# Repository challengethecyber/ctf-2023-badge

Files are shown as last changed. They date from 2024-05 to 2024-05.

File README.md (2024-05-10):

# ctf-2023-badge
Badge related files for CTC 2023 CTF



## Info

- Custom PCB with RP2040 based on [rp-micro](https://github.com/siderakb/rp-micro) project.
- View [IBOM](https://challengethecyber.github.io/ctf-2023-assets/ducky/ibom.html)

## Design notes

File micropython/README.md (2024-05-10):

uf2 created from
 - circuitpython base
 - duckyfs files added on top of it
 - filesystem renamed (in windows) to DUCKY

then ran:
# sudo picotool save -a -f -t uf2 ducky.uf2

to load it onto another ducky:
# sudo picotool load ducky.uf2

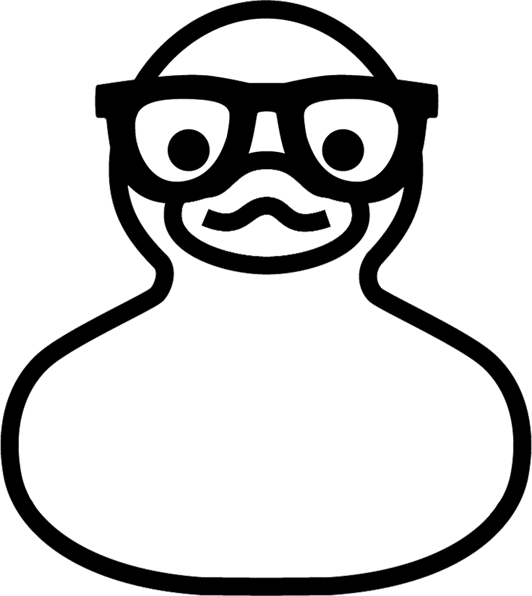
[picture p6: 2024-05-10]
hardware/psd/v2-duck-10cm-lines-noarms.png

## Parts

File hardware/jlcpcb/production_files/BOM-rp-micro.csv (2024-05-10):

Comment | Designator | Footprint | LCSC
1k | R3,R4,R9 | R_0402_1005Metric | C11702
B5817 | D1 | D_SOD-323_HandSoldering | C123899
20pF | C3,C4 | C_0402_1005Metric | C1554
RP2040 | U1 | QFN-56-1EP_7x7mm_P0.4mm_EP3.2x3.2mm | C2040
BOOT | SW1,SW2 | SW_SPST_B3U-1000P | C231329
27 | R1,R2 | R_0402_1005Metric | C25100
10k | R5,R8 | R_0402_1005Metric | C25744
5.1k | R6,R7 | R_0402_1005Metric | C25905
500mA, 6V | F1 | Fuse_0805_2012Metric | C269104
W25Q64JVXGIQ | U2 | XSON-8 (4x4mm) | C2940195
100nF | C1,C10,C11,C12,C15,C2,C5,C6,C8,C9 | C_0402_1005Metric | C307331
RT9013-33GB | U3 | SOT-23-5 | C47773
1uF | C13,C14,C16,C7 | C_0402_1005Metric | C52923
BLUE | LD1 | LED_0603_1608Metric | C72041
12MHz | Y1 | Crystal_SMD_3225-4Pin_3.2x2.5mm | C9002
USB_C_Receptacle_USB2.0 | J1 | USB_C_Receptacle_TYPE-C-31-M-12

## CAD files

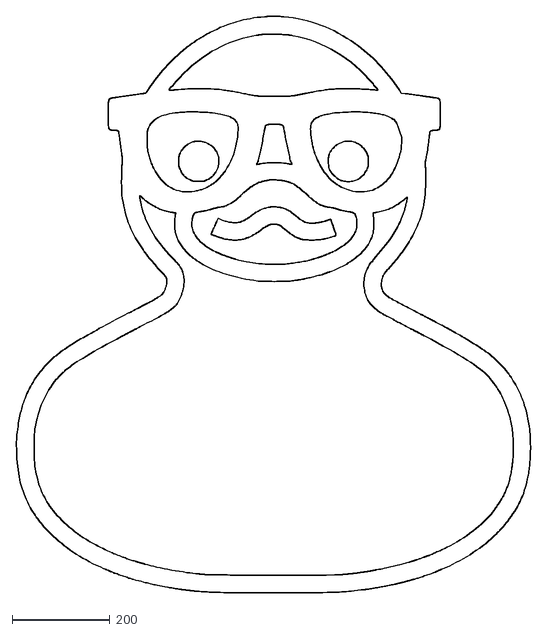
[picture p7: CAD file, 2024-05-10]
hardware/psd/v2-duck-10cm-lines-noarms.dxf
1051.7 x 1180.5

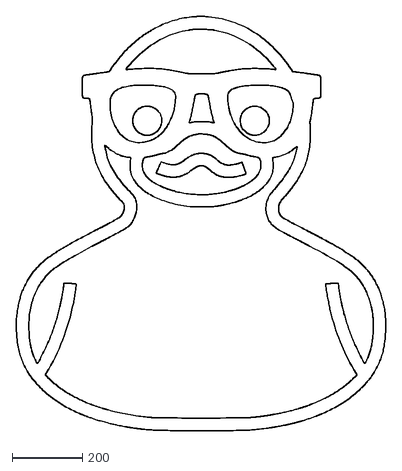
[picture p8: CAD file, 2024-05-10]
hardware/psd/v2-duck-10cm-lines.dxf
1051.7 x 1180.5

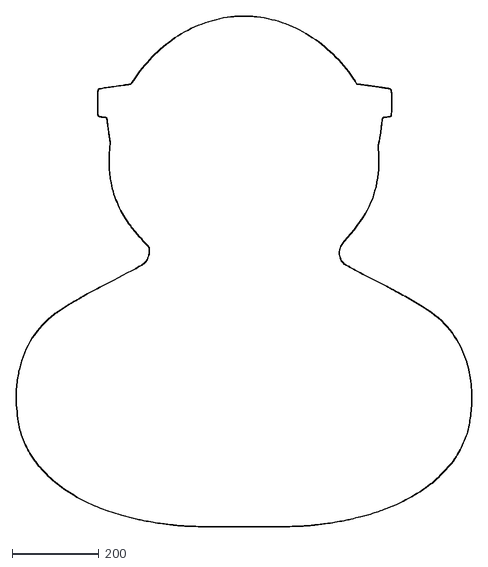
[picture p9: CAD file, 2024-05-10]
hardware/psd/v2-duck-10cm-bw.dxf
1052.4 x 1178.8

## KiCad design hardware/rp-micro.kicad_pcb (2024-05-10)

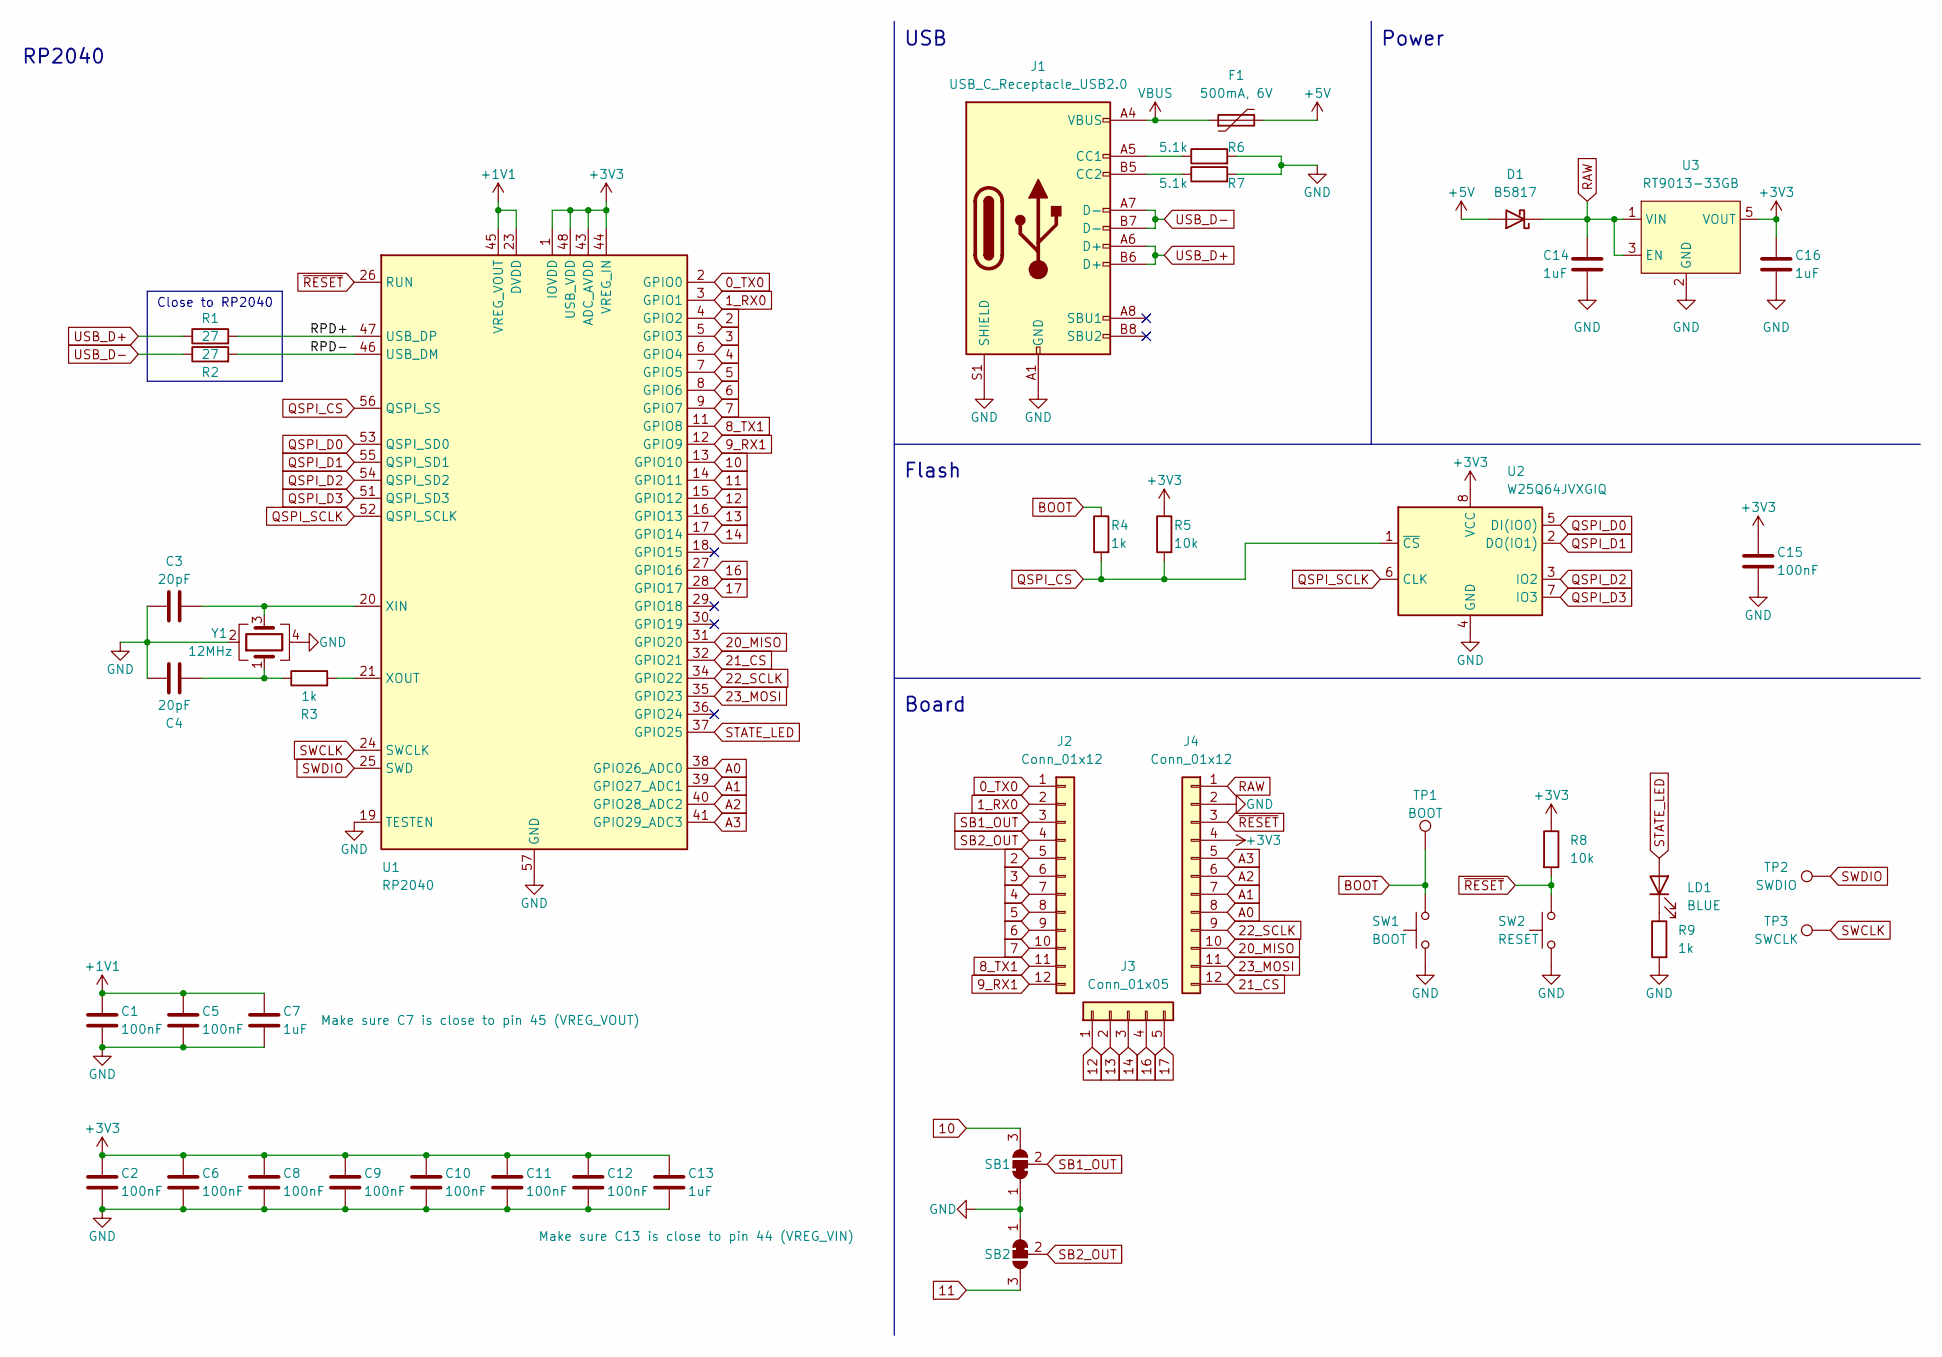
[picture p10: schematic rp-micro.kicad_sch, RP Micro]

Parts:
C1, C2, C5, C6, C8, C9, C10, C11, C12, C15: 100nF; C_0402_1005Metric; MFR. Part # CL05B104KB54PNC; JLCPCB Part # C307331
C3, C4: 20pF; C_0402_1005Metric; MFR. Part # 0402CG200J500NT; JLCPCB Part # C1554
C7, C13, C14, C16: 1uF; C_0402_1005Metric; MFR. Part # CL05A105KA5NQNC; JLCPCB Part # C52923
D1: B5817; D_SOD-323_HandSoldering; MFR. Part # B5817WS; JLCPCB Part # C123899
F1: 500mA, 6V; Fuse_0805_2012Metric; MFR. Part # SMD0805B050TF; JLCPCB Part # C269104
J1: USB_C_Receptacle_USB2.0; USB Type-C Mid-Mount Receptacle 16P; MFR. Part # 918-418K2024S40000; JLCPCB Part # C168688
J2, J4: Conn_01x12; PinHeader_1x12_P2.54mm_Vertical
J3: Conn_01x05; PinHeader_1x05_P2.54mm_Vertical
LD1: BLUE; LED_0603_1608Metric; MFR. Part # 19-217/BHC-ZL1M2RY/3T; JLCPCB Part # C72041
R1, R2: 27; R_0402_1005Metric; MFR. Part # 0402WGF270JTCE; JLCPCB Part # C25100
R3, R4, R9: 1k; R_0402_1005Metric; MFR. Part # 0402WGF1001TCE; JLCPCB Part # C11702
R5, R8: 10k; R_0402_1005Metric; MFR. Part # 0402WGF1002TCE; JLCPCB Part # C25744
R6, R7: 5.1k; R_0402_1005Metric; MFR. Part # 0402WGF5101TCE; JLCPCB Part # C25905
SB1, SB2: SolderJumper_3_Bridged12; SolderJumper-3_P1.3mm_Bridged12_Pad1.0x1.5mm
SW1: BOOT; SW_SPST_B3U-1000P; MFR. Part # B3U-1000P; JLCPCB Part # C231329
SW2: RESET; SW_SPST_B3U-1000P; MFR. Part # B3U-1000P; JLCPCB Part # C231329
TP1: BOOT; TestPoint_Pad_D2.0mm
TP2: SWDIO; TestPoint_Pad_D2.0mm
TP3: SWCLK; TestPoint_Pad_D2.0mm
U1: RP2040; QFN-56-1EP_7x7mm_P0.4mm_EP3.2x3.2mm; MFR. Part # RP2040; JLCPCB Part # C2040
U2: W25Q64JVXGIQ; XSON-8 (4x4mm); MFR. Part # W25Q64JVXGIQ; JLCPCB Part # C2940195
U3: RT9013-33GB; SOT-23-5; MFR. Part # RT9013-33GB; JLCPCB Part # C47773
Y1: 12MHz; Crystal_SMD_3225-4Pin_3.2x2.5mm; MFR. Part # X322512MSB4SI; JLCPCB Part # C9002

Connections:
0_TX0: J2.1, U1.2 (GPIO0)
1_RX0: J2.2, U1.3 (GPIO1)
2: J2.5, U1.4 (GPIO2)
3: J2.6, U1.5 (GPIO3)
4: J2.7, U1.6 (GPIO4)
5: J2.8, U1.7 (GPIO5)
6: J2.9, U1.8 (GPIO6)
7: J2.10, U1.9 (GPIO7)
8_TX1: J2.11, U1.11 (GPIO8)
9_RX1: J2.12, U1.12 (GPIO9)
10: SB1.3 (B), U1.13 (GPIO10)
11: SB2.3 (B), U1.14 (GPIO11)
12: J3.1, U1.15 (GPIO12)
13: J3.2, U1.16 (GPIO13)
14: J3.3, U1.17 (GPIO14)
16: J3.4, U1.27 (GPIO16)
17: J3.5, U1.28 (GPIO17)
20_MISO: J4.10, U1.31 (GPIO20)
21_CS: J4.12, U1.32 (GPIO21)
22_SCLK: J4.9, U1.34 (GPIO22)
23_MOSI: J4.11, U1.35 (GPIO23)
+1V1: C1.1, C5.1, C7.1, U1.23 (DVDD), U1.45 (VREG_VOUT), U1.50 (DVDD)
+3V3: C2.1, C6.1, C8.1, C9.1, C10.1, C11.1, C12.1, C13.1, C15.1, C16.1, J4.4, R5.1, R8.1, U1.1 (IOVDD), U1.10 (IOVDD), U1.22 (IOVDD), U1.33 (IOVDD), U1.42 (IOVDD), U1.43 (ADC_AVDD), U1.44 (VREG_IN), U1.48 (USB_VDD), U1.49 (IOVDD), U2.8 (VCC), U3.5 (VOUT)
+5V: D1.2 (A), F1.2
/RPD+: R1.2, U1.47 (USB_DP)
/RPD-: R2.2, U1.46 (USB_DM)
A0: J4.8, U1.38 (GPIO26_ADC0)
A1: J4.7, U1.39 (GPIO27_ADC1)
A2: J4.6, U1.40 (GPIO28_ADC2)
A3: J4.5, U1.41 (GPIO29_ADC3)
BOOT: R4.1, SW1.2, TP1.1
GND: C1.2, C2.2, C3.1, C4.1, C5.2, C6.2, C7.2, C8.2, C9.2, C10.2, C11.2, C12.2, C13.2, C14.2, C15.2, C16.2, J1.A1 (GND), J1.A12 (GND), J1.B1 (GND), J1.B12 (GND), J1.S1 (SHIELD), J4.2, R6.2, R7.2, R9.2, SB1.1 (A), SB2.1 (A), SW1.1, SW2.1, U1.19 (TESTEN), U1.57 (GND), U2.4 (GND), U3.2 (GND), Y1.2, Y1.4
unnamed: C3.2, U1.20 (XIN), Y1.3
unnamed: C4.2, R3.1, Y1.1
unnamed: J1.A5 (CC1), R6.1
unnamed: J1.B5 (CC2), R7.1
unnamed: LD1.1 (K), R9.1
unnamed: R3.2, U1.21 (XOUT)
QSPI_CS: R4.2, R5.2, U1.56 (QSPI_SS), U2.1 (~CS)
QSPI_D0: U1.53 (QSPI_SD0), U2.5 (DI(IO0))
QSPI_D1: U1.55 (QSPI_SD1), U2.2 (DO(IO1))
QSPI_D2: U1.54 (QSPI_SD2), U2.3 (IO2)
QSPI_D3: U1.51 (QSPI_SD3), U2.7 (IO3)
QSPI_SCLK: U1.52 (QSPI_SCLK), U2.6 (CLK)
RAW: C14.1, D1.1 (K), J4.1, U3.1 (VIN), U3.3 (EN)
SB1_OUT: J2.3, SB1.2 (C)
SB2_OUT: J2.4, SB2.2 (C)
STATE_LED: LD1.2 (A), U1.37 (GPIO25)
SWCLK: TP3.1, U1.24 (SWCLK)
SWDIO: TP2.1, U1.25 (SWD)
USB_D+: J1.A6 (D+), J1.B6 (D+), R1.1
USB_D-: J1.A7 (D-), J1.B7 (D-), R2.1
VBUS: F1.1, J1.A4 (VBUS), J1.A9 (VBUS), J1.B4 (VBUS), J1.B9 (VBUS)
~RESET: J4.3, R8.2, SW2.2, U1.26 (RUN)

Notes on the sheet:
Flash
Close to RP2040
Power
RP2040
USB
Board

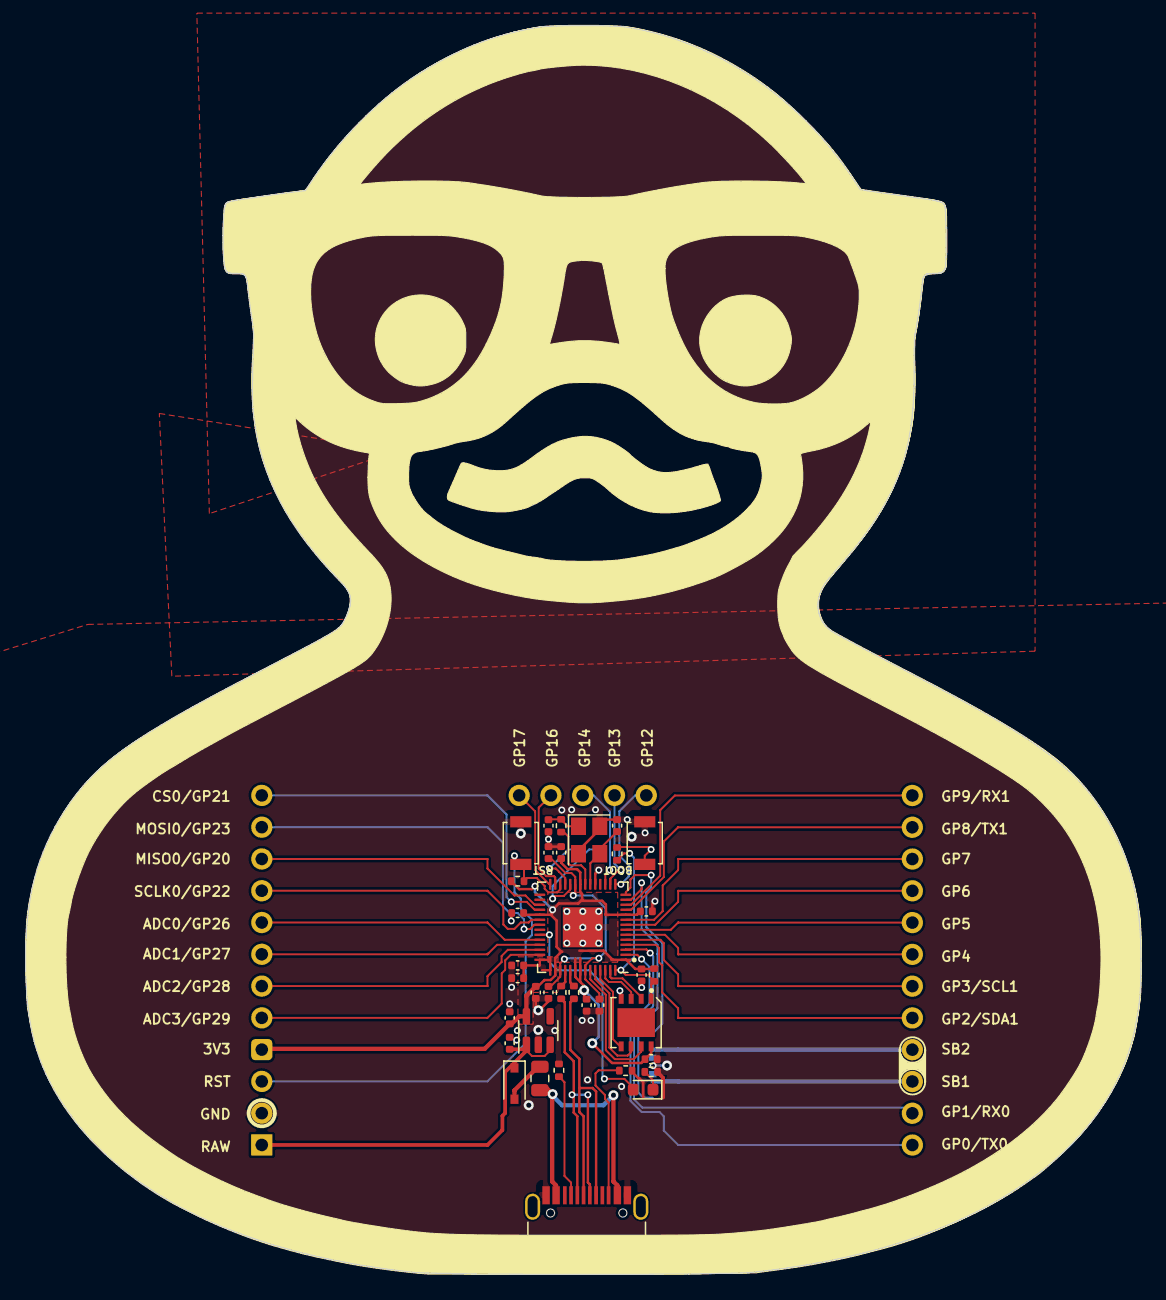
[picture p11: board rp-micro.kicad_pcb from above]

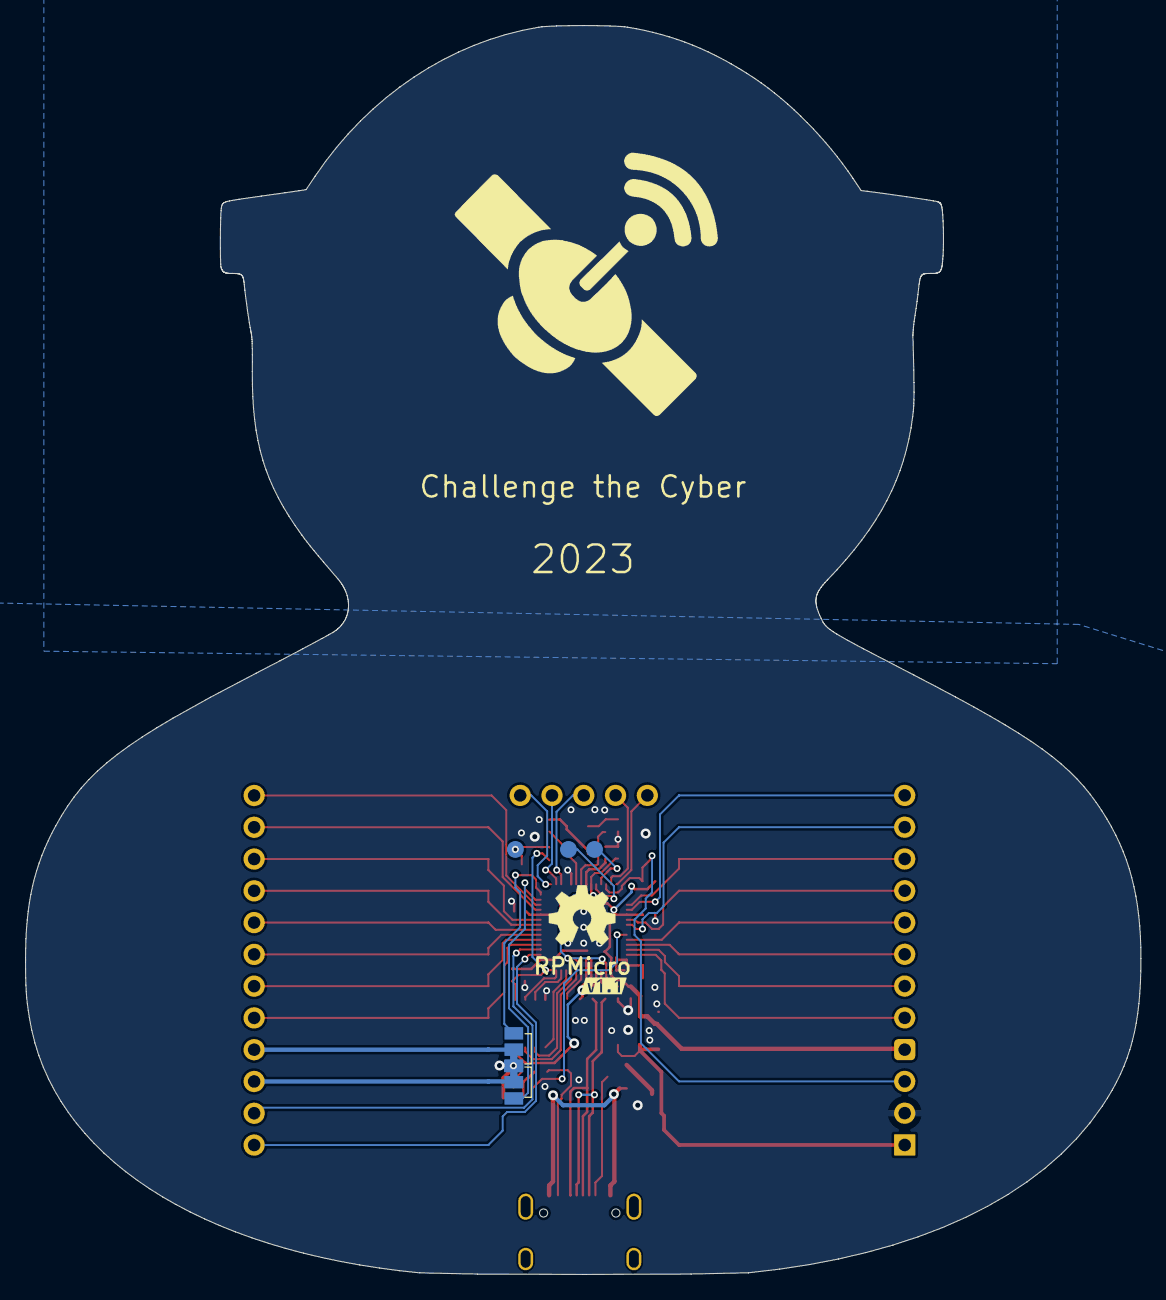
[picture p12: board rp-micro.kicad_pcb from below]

Board: 2 copper layers, 89.2 x 99.8 mm, 44 parts (8 on the bottom side), 54 nets.

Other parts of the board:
kibuzzard-637CA201: G***; kibuzzard-637CA201

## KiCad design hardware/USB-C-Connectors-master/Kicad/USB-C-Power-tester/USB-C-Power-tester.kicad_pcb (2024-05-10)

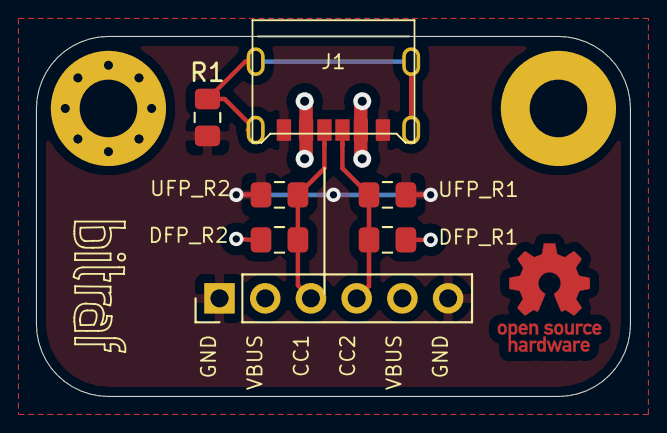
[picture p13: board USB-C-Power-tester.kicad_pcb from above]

Board: 2 copper layers, 33.0 x 20.0 mm, 11 parts (0 on the bottom side), 5 nets.

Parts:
DFP_R1, DFP_R2: DFP; R_0805_2012Metric_Pad1.15x1.40mm_HandSolder
H1: MountingHole; MountingHole_3.2mm_M3_Pad_Via
H3: MountingHole; MountingHole_3.2mm_M3_Pad
J1: USB_C_Receptacle_USB2.0; TYPE-C-31-M-17
L1: Logo_Open_Hardware_Small; OSHW-Logo_5.7x6mm_Copper
L2: Logo_Open_Hardware_Small; Bitraf_logo_3.0_x_7.5_mm
PIN1: Screw_Terminal_01x06; PinHeader_1x06_P2.54mm_Vertical
R1: 1M; R_0805_2012Metric_Pad1.15x1.40mm_HandSolder
UFP_R1, UFP_R2: UFP; R_0805_2012Metric_Pad1.15x1.40mm_HandSolder

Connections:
GND: J1.A12, J1.B12, PIN1.1, PIN1.6, R1.1, UFP_R1.2, UFP_R2.2
unnamed: DFP_R1.1, J1.A5, PIN1.4, UFP_R1.1
unnamed: DFP_R2.1, J1.B5, PIN1.3, UFP_R2.1
unnamed: J1.S1, R1.2
VBUS: DFP_R1.2, DFP_R2.2, J1.A9, J1.B9, PIN1.2, PIN1.5

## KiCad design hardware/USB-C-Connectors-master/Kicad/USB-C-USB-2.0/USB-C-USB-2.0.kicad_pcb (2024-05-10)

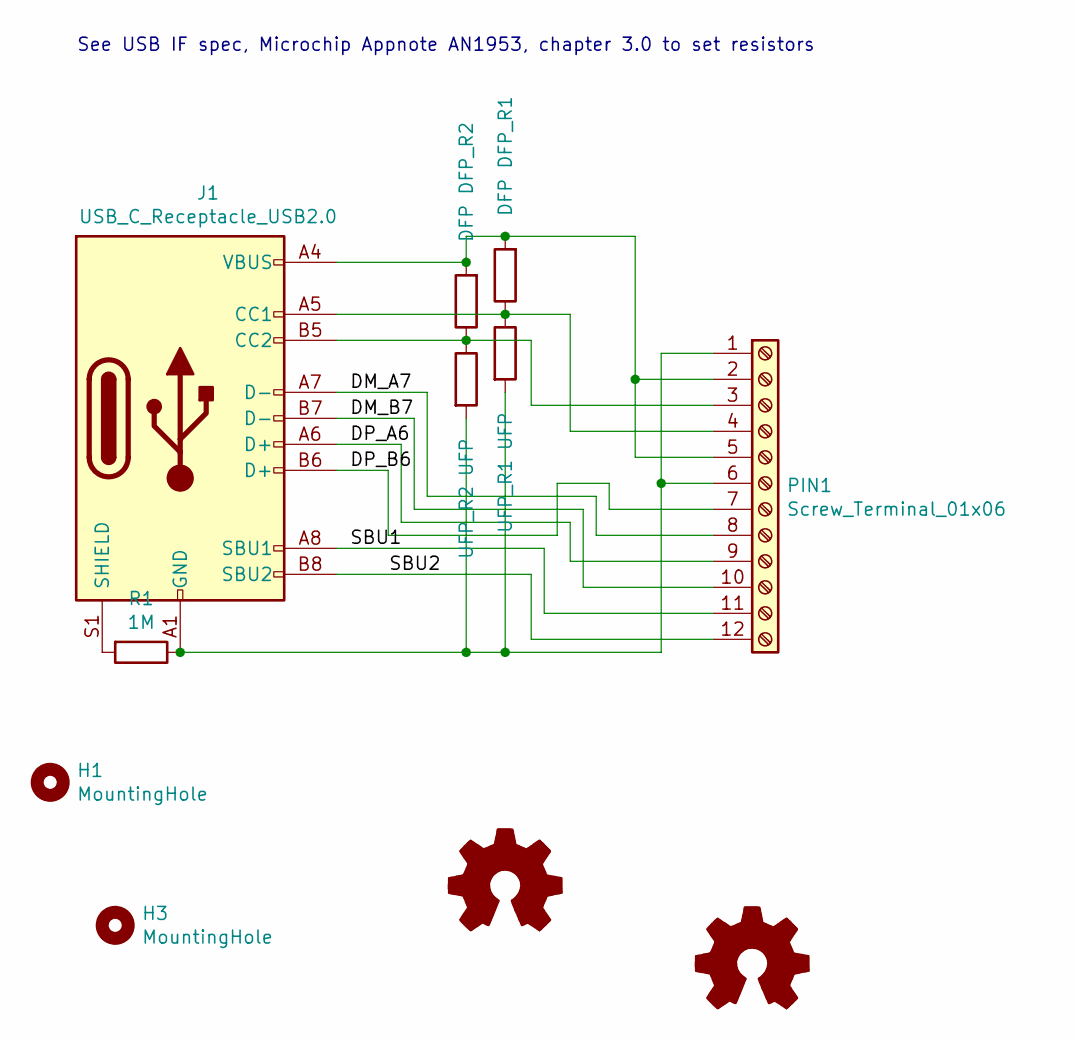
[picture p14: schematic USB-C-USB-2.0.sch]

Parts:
DFP_R1, DFP_R2: DFP; R_0805_2012Metric_Pad1.15x1.40mm_HandSolder
H1: MountingHole; MountingHole_3.2mm_M3_Pad_Via
H3: MountingHole; MountingHole_3.2mm_M3_Pad
J1: USB_C_Receptacle_USB2.0; TYPE-C-31-M-12; MPN TYPE-C-31-M-17
L1: Logo_Open_Hardware_Small; OSHW-Logo_5.7x6mm_SilkScreen
L2: Logo_Open_Hardware_Small; Bitraf_logo_3.0_x_7.5_mm
PIN1: Screw_Terminal_01x06; PinHeader_1x12_P2.54mm_Vertical
R1: 1M; R_0805_2012Metric_Pad1.15x1.40mm_HandSolder
UFP_R1, UFP_R2: UFP; R_0805_2012Metric_Pad1.15x1.40mm_HandSolder

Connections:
/DM_A7: J1.A7 (D-), PIN1.8
/DM_B7: J1.B7 (D-), PIN1.10
/DP_A6: J1.A6 (D+), PIN1.9
/DP_B6: J1.B6 (D+), PIN1.7
/SBU1: J1.A8 (SBU1), PIN1.11
/SBU2: J1.B8 (SBU2), PIN1.12
GND: J1.A1 (GND), J1.A12 (GND), J1.B1 (GND), J1.B12 (GND), PIN1.1, PIN1.6, R1.1, UFP_R1.2, UFP_R2.2
unnamed: DFP_R1.1, J1.A5 (CC1), PIN1.4, UFP_R1.1
unnamed: DFP_R2.1, J1.B5 (CC2), PIN1.3, UFP_R2.1
unnamed: J1.S1 (SHIELD), R1.2
VBUS: DFP_R1.2, DFP_R2.2, J1.A4 (VBUS), J1.A9 (VBUS), J1.B4 (VBUS), J1.B9 (VBUS), PIN1.2, PIN1.5

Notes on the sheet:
See USB IF spec, Microchip Appnote AN1953, chapter 3.0 to set resistors

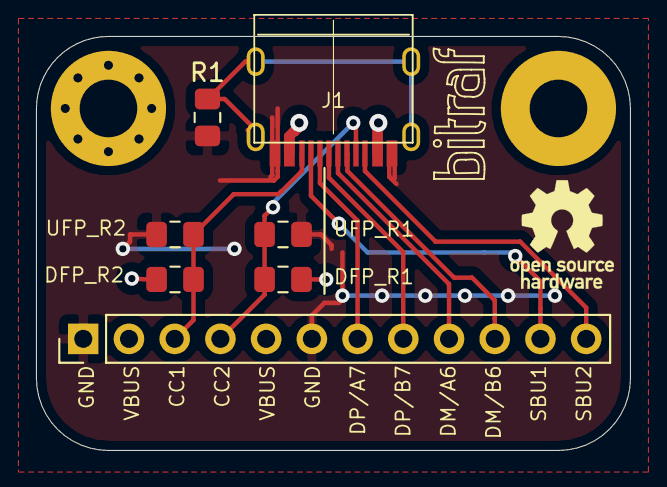
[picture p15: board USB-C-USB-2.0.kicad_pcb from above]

Board: 2 copper layers, 33.0 x 23.0 mm, 11 parts (0 on the bottom side), 11 nets.

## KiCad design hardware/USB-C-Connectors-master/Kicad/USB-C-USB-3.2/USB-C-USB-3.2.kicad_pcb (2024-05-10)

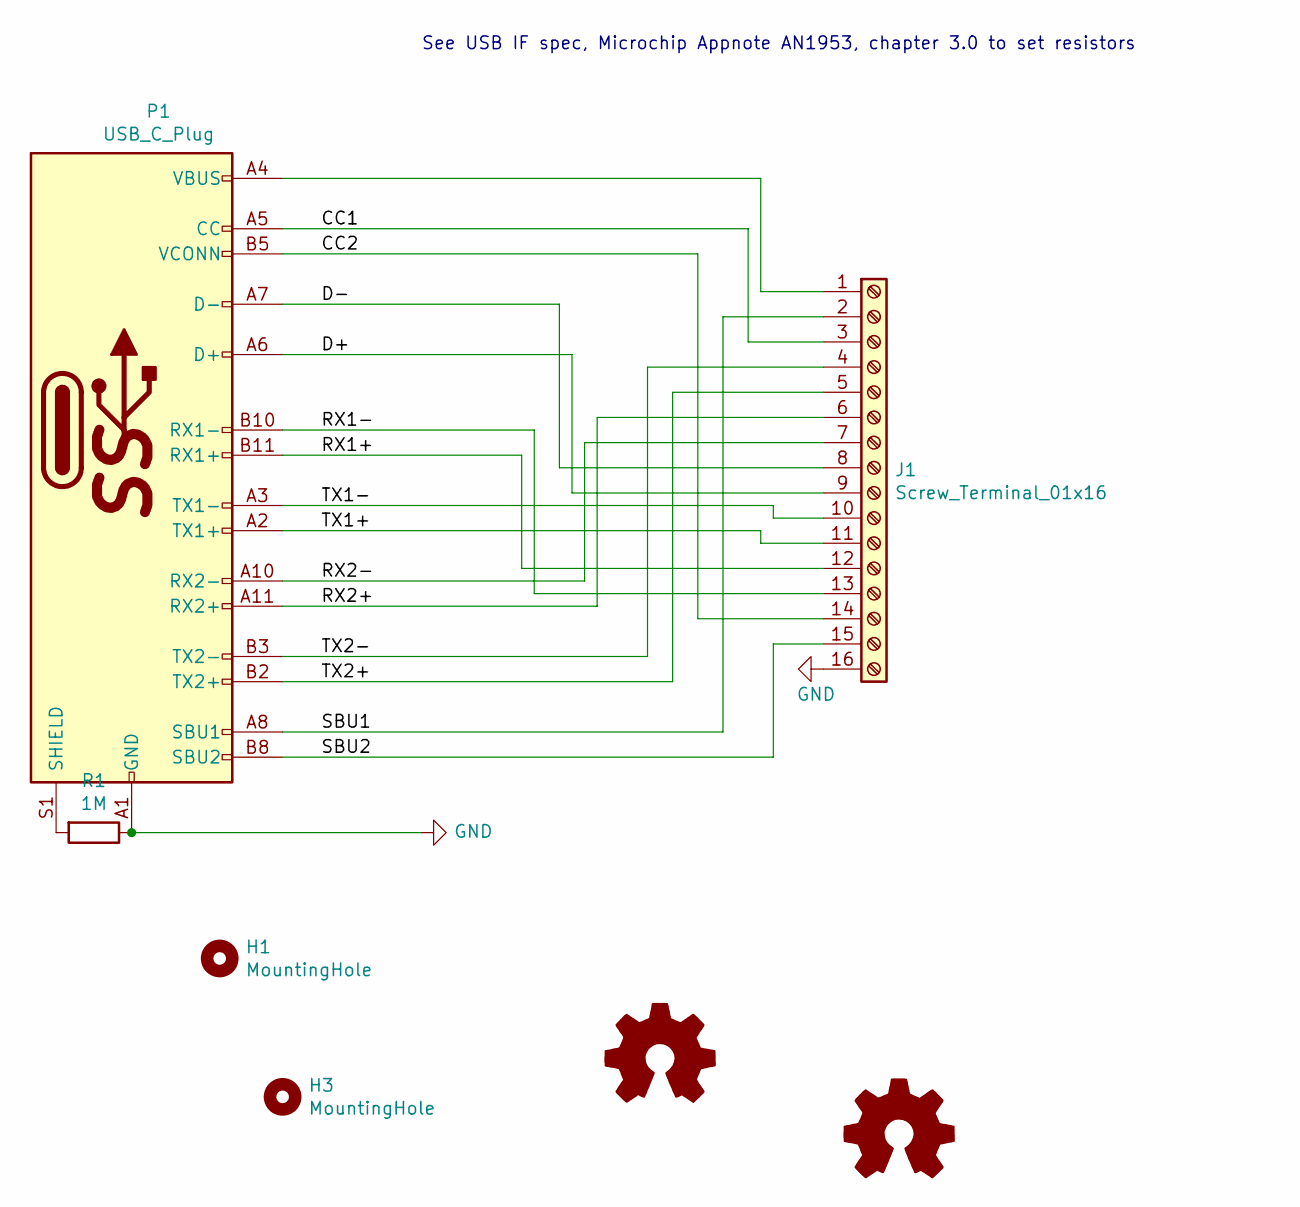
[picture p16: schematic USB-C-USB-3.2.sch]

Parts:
H1: MountingHole; MountingHole_3.2mm_M3_Pad_Via
H3: MountingHole; MountingHole_3.2mm_M3_Pad
J1: Screw_Terminal_01x16; PinHeader_1x16_P2.54mm_Vertical
L1: Logo_Open_Hardware_Small; OSHW-Logo_5.7x6mm_Copper
L2: Logo_Open_Hardware_Small; Bitraf_logo_3.0_x_7.5_mm
P1: USB_C_Plug; USB_C_Receptacle_Amphenol_12401548E4-2A
R1: 1M; R_0805_2012Metric_Pad1.15x1.40mm_HandSolder

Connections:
/CC1: J1.3, P1.A5 (CC)
/CC2: J1.14, P1.B5 (VCONN)
/D+: J1.9, P1.A6 (D+)
/D-: J1.8, P1.A7 (D-)
/RX1+: J1.12, P1.B11 (RX1+)
/RX1-: J1.13, P1.B10 (RX1-)
/RX2+: J1.6, P1.A11 (RX2+)
/RX2-: J1.7, P1.A10 (RX2-)
/SBU1: J1.2, P1.A8 (SBU1)
/SBU2: J1.15, P1.B8 (SBU2)
/TX1+: J1.11, P1.A2 (TX1+)
/TX1-: J1.10, P1.A3 (TX1-)
/TX2+: J1.5, P1.B2 (TX2+)
/TX2-: J1.4, P1.B3 (TX2-)
GND: J1.16, P1.A1 (GND), P1.A12 (GND), P1.B1 (GND), P1.B12 (GND), R1.1
unnamed: P1.S1 (SHIELD), R1.2
VBUS: J1.1, P1.A4 (VBUS), P1.A9 (VBUS), P1.B4 (VBUS), P1.B9 (VBUS)

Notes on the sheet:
See USB IF spec, Microchip Appnote AN1953, chapter 3.0 to set resistors

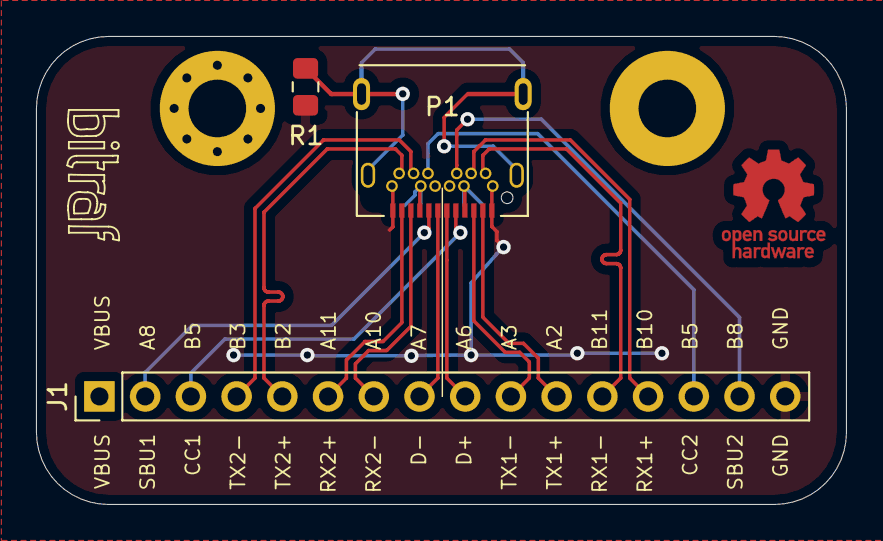
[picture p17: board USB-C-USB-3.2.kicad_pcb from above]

Board: 2 copper layers, 45.0 x 26.0 mm, 7 parts (0 on the bottom side), 17 nets.

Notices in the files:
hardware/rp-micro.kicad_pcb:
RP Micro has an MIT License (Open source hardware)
